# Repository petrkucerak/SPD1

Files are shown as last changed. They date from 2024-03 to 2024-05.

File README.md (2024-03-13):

# Weather station with geolocation

Authors: Petr Kucera, Lukas Nejezchleb

## Project description

### Goal and motivation

If you go for cold water swimming, it might be interesting for you to know the parameters of the particular river, stream, or pond. But how do you manage when the Czech Hydrometeorological Institute does not monitor the given watercourse? What if you could keep a diary that would not only collect the water and air temperature but also allow you to record how you felt on a particular day after the cold swimming?

The aim of this project is to create weather station capable of measuring temperature, humidity, water temperature, light. In addition, the station will be equipped with GPS sensor, so that the user can distinguish between data from different stations using positions in the map. 

### Use case
Various weather station projects are currently available. When we consider the requirement to have multiple weather stations (there can be quite different weather conditions in locations close-by, especially in mountainous terrain). Our approach, which uses GPS positioning to distinguish between different nodes, could help with that.

### Project architecture

For simplicity, let's divide the project into two environments: *river environment* and *house environment*.

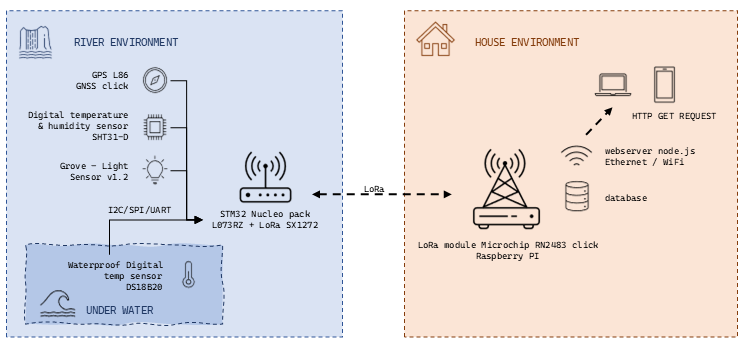
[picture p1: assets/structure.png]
project structure


The **river environment** includes a device that is placed on the riverbank. One sensor, measuring water temperature, is located in the water, while other sensors measuring temperature and humidity, position (GPS), and light are placed above the water. The device operates hourly and is powered by batteries. It sends data several times a day using LoRa technology. Code will be implemented in C/C++.

In the **house environment**, there is a device called the *concentrator*. It receives data from devices by the watercourse using LoRa technology and stores it in a database. The device is connected to the home network via RJ-45 or WiFi. It runs a web server that displays the measured results on a map. Handle routines will be implemented in C/C++/Python and server in JavaScript/Typescript.

## Requirements
To implement a weather station node, the following material is required
- STM32 Nucleo pack - L073RZ + LoRa SX1272 (*2x for parallel development*)
- GPS L86 - GNSS click
- SHT31-D Digital temperature & humidity sensor
- Grove - Light Sensor v1.2
- DS18B20 Waterproof Digital temp sensor 

For master bus collecting data from nodes
- Raspberry Pi 3 B + LoRa shield + 32GB SD

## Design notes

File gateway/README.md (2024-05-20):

# Gateway device

LoRa Gateway device runs on Raspberry PI.

## Connect to Raspberry PI

```sh
ssh pedro@192.168.0.178
ssh pedro@192.168.137.157
K&mo1234 # password
```

## Hardware

### Lora shield

- LoRa Gateway RPI/RFI
- pinout: https://electronilab.co/tienda/modulo-transceptor-rfm96w-hoperf-lora-ultra-long-range-433-mhz/
- datasheet: https://cdn-learn.adafruit.com/assets/assets/000/031/660/original/sx1272.pdf?1460518722

```
    H
   rf96
 17081714
1708122155
```

## Software

Uses https://github.com/adafruit/Adafruit_CircuitPython_RFM9x

```sh
python3 -m venv .venv
source .venv/bin/activate
pip3 install adafruit-circuitpython-rfm9x
```

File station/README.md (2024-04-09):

# Station device

Station runs on ST32 based board.

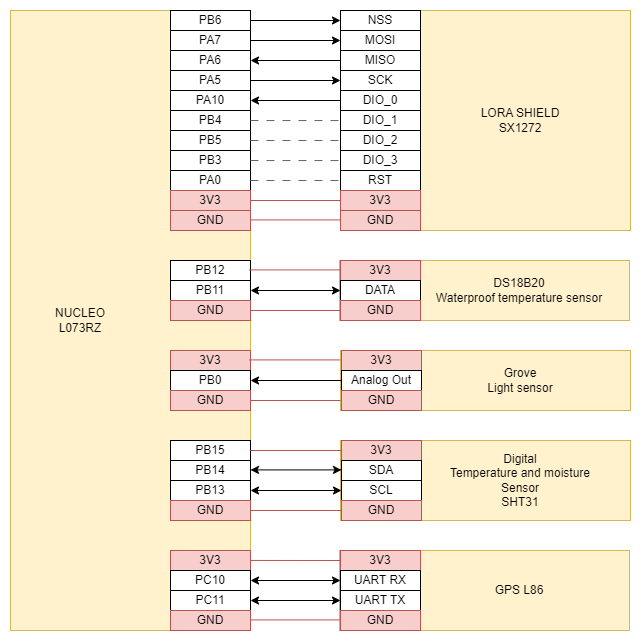
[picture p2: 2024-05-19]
station/Schematic.png

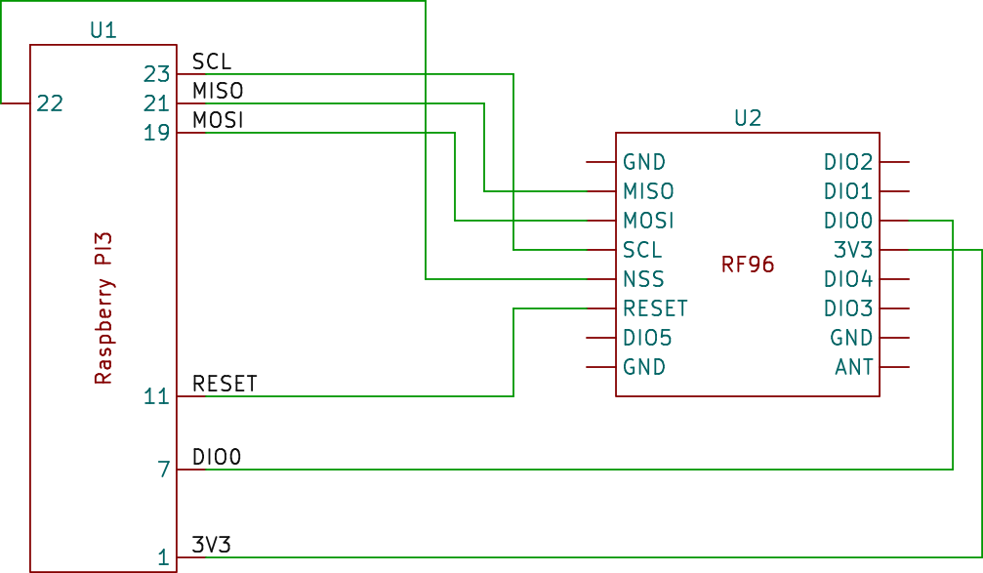
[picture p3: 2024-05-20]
gateway/gateway-schema/gateway-schema.png

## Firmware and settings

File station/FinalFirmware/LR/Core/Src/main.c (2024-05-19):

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
/* Includes ------------------------------------------------------------------*/
#include "main.h"

/* USER CODE BEGIN Includes */
#include <math.h>
#include <stdlib.h>
#include <stdio.h>

/* USER CODE END Includes */

/* USER CODE BEGIN PD */
#define SERVER 0
uint8_t data_rx [512] = {0};
uint8_t data_tx [512] = {0};
uint8_t last_data_received = 0;
uint16_t last_data_num;

/* USER CODE END PD */

 ADC_HandleTypeDef hadc;
DMA_HandleTypeDef hdma_adc;

I2C_HandleTypeDef hi2c2;

SPI_HandleTypeDef hspi1;

TIM_HandleTypeDef htim6;
TIM_HandleTypeDef htim21;

UART_HandleTypeDef huart2;
UART_HandleTypeDef huart4;
DMA_HandleTypeDef hdma_usart2_tx;
DMA_HandleTypeDef hdma_usart4_rx;

void SystemClock_Config(void);
static void MX_GPIO_Init(void);
static void MX_USART2_UART_Init(void);
static void MX_DMA_Init(void);
static void MX_USART4_UART_Init(void);
static void MX_ADC_Init(void);
static void MX_SPI1_Init(void);
static void MX_TIM6_Init(void);
static void MX_TIM21_Init(void);
static void MX_I2C2_Init(void);
/* USER CODE BEGIN 0 */
float last_valid_latt = 0;
float last_valid_long = 0;
float last_valid_time = 0;
char last_valid_ns = 0;
char last_valid_we = 0;

uint16_t last_transmission_ID = 0;
uint8_t last_transmission_Checksum = 0;
uint8_t last_transmission_BitwiseParity = 0;
uint8_t last_transmission_confirmed = 0;





#define RXBUFLEN  4096
#define ADCDATALEN 2
char rx_data [RXBUFLEN] = {0};
uint16_t last_rx = 0;
#define RXLINBUFLEN 128
char rx_lin_buf [RXLINBUFLEN+1]= {0};

char tempbuffer [] = "$GNGLL,5005.2816,N,01427.1765,E,102908.000,A,D*48\r\n";

#define TXBUFLEN 110
char txbuf [TXBUFLEN] = {0};

uint16_t adcdata [ADCDATALEN] = {0};


enum msg_types {msg_unknown, msg_gnss_pos, msg_gnss_sat, msg_gps_pos, msg_gps_sat};

char* str_msg_gnss_pos = "$GNGLL";
char* str_msg_gps__pos = "$GPGLL";


//functions

uint8_t random_bit(){
	return adcdata[1]&1;
}

uint16_t random_uin16_t(){
	uint16_t random_code = 0;
	for(int i=0; i<16; ++i){
		random_code = random_code<<1;
		random_code = random_code|random_bit();
		HAL_Delay(5);
	}
	return random_code;
}

uint8_t strings_match_six(char *a, char* b){
	for(int i=0; i<6; ++i){
		if(a[i]!= b[i]){
			return 0;
		}
	}
	return 1;
}



uint8_t get_msg_type(){
	uint8_t msg_type = msg_unknown;
	if(rx_lin_buf[0]=='$'){
		if(strings_match_six(rx_lin_buf, str_msg_gnss_pos)){
			msg_type = msg_gnss_pos;
		}
		if(strings_match_six(rx_lin_buf, str_msg_gps__pos)){
			msg_type = msg_gps_pos;
		}

	}
	return msg_type;
}

int transfer_to_lin_buf(){
	//transfers one gps message into linear buffer
	int i=0;
	int end_found = 0;
	for(i=0; i<RXLINBUFLEN;++i){
		int idx = (last_rx+i)%RXBUFLEN;
		if(rx_data[idx] == '*'){
			if(rx_data[(idx+1)%RXBUFLEN]!=0){
				if(rx_data[(idx+2)%RXBUFLEN]!=0){
					end_found = 1;
				}
			}
			break;
		}
	}
	if(end_found==1){
		for(int j=0; j<=i+4; ++j){
			int idx = (last_rx+j)%RXBUFLEN;
			rx_lin_buf[j] = rx_data[idx];
			rx_data[idx] = 0;
		}
		for(int j=i+4+1; j<RXLINBUFLEN; ++j){
			rx_lin_buf[j] = 0;
		}
		last_rx = (last_rx+i+5)%RXBUFLEN;
	}
	return end_found;
}

uint8_t decode_gps(float *lat, float *lon, float* time, char *ns, char *we){
	//returns 1 if data is valid
	char valid = 0;

	char *endptr;
	char* parsedtext = &rx_lin_buf[7];
	*lat = strtof(parsedtext, &endptr);
	if(endptr[1]!=','){
		*ns = endptr[1];
		endptr= endptr+3;
	}else{
		endptr = endptr+2;
	}
	parsedtext = endptr;
	*lon = strtof(parsedtext, &endptr);
	if(endptr[1]!=','){
		*we = endptr[1];
		endptr= endptr+3;
	}else{
		endptr = endptr+2;
	}

	parsedtext = endptr;
	*time = strtof(parsedtext, &endptr);
	if(endptr[1]!=','){
		valid = endptr[1];
		endptr= endptr+3;
	}else{
		endptr = endptr+2;
	}

	//convert the values to degrees
	*lat = *lat/100;
	*lat = (floor(*lat)+(*lat-floor(*lat))/60.0*100.0);
	*lon = *lon/100;
	*lon = (floor(*lon)+(*lon-floor(*lon))/60.0*100.0);
	return(valid == 'A');
}

void handle_gps(){
	while(transfer_to_lin_buf()){
		uint8_t msg_type=  get_msg_type();
		if(msg_type == msg_gnss_pos || msg_type== msg_gps_pos){
			float temp_lat = 0;
			float temp_time = 0;
			float temp_long = 0;
			char temp_ns =0;
			char temp_we =0;
			if(decode_gps(&temp_lat, &temp_long, &temp_time, &temp_ns, &temp_we)){
				last_valid_latt = temp_lat;
				last_valid_long = temp_long;
				last_valid_time = temp_time;
				last_valid_ns = temp_ns;
				last_valid_we = temp_we;
			}
		}
	}

}






void delay_us (uint32_t us)
{
    __HAL_TIM_SET_COUNTER(&htim21,0);
    while ((__HAL_TIM_GET_COUNTER(&htim21))<us);
}

uint8_t DS18B20_Start (void)
{
	uint8_t Response = 0;
	GPIOB->BRR |= TEMPSIG_Pin; //reset pin
	delay_us (480);   // delay according to datasheet
	GPIOB->BSRR |= TEMPSIG_Pin; //reset pin
	delay_us (80);    // delay according to datasheet

	if (!(HAL_GPIO_ReadPin (TEMPSIG_GPIO_Port, TEMPSIG_Pin))) Response = 1;    // if the pin is low i.e the presence pulse is detected
	else Response = 0;

	delay_us (400); // 480 us delay totally.

	return Response;
}

void DS18B20_Write (uint8_t data)
{

	for (int i=0; i<8; i++)
	{

		if ((data & (1<<i))!=0)  // if the bit is high
		{
			// write 1
			GPIOB->BRR |= TEMPSIG_Pin; //reset pin
			delay_us (1);  // wait for 1 us

			GPIOB->BSRR |= TEMPSIG_Pin; //reset pin
			delay_us (70);  // wait for 60 us
		}

		else  // if the bit is low
		{
			// write 0
			GPIOB->BRR |= TEMPSIG_Pin; //reset pin
			delay_us (70);  // wait for 60 us

			GPIOB->BSRR |= TEMPSIG_Pin; //reset pin
			delay_us (1);  // wait for 1 us
		}
	}

}

uint8_t DS18B20_Read (void)
{
	uint8_t value=0;
	HAL_GPIO_WritePin(TEMPSIG_GPIO_Port, TEMPSIG_Pin, GPIO_PIN_SET);

	for (int i=0;i<8;i++)
	{
		GPIOB->BRR |= TEMPSIG_Pin; //reset pin
		//HAL_GPIO_WritePin(TEMPSIG_GPIO_Port, TEMPSIG_Pin, GPIO_PIN_RESET);
		delay_us (1);  // wait for 3 us
		GPIOB->BSRR |= TEMPSIG_Pin; //reset pin
		delay_us (1);
		//HAL_GPIO_WritePin(TEMPSIG_GPIO_Port, TEMPSIG_Pin, GPIO_PIN_SET);
		if (HAL_GPIO_ReadPin (TEMPSIG_GPIO_Port, TEMPSIG_Pin))  // if the pin is HIGH
		{
			value |= 1<<i;  // read = 1
		}
		delay_us (70);  // wait for 60 us
	}
	return value;
}

float get_DS18B20_temp(void){

	float floattemp = 0;

	__disable_irq();  // disable all interrupts
		if(DS18B20_Start ()){ //sensor detected
		__enable_irq();   // enable all interrupts
		HAL_Delay (1);
		__disable_irq();  // disable all interrupts
		DS18B20_Write (0xCC);  // skip ROM
		DS18B20_Write (0x44);  // convert t
		__enable_irq();   // enable all interrupts
		HAL_Delay (800);
		__disable_irq();  // disable all interrupts
		if(DS18B20_Start ()){
			__enable_irq();   // enable all interrupts
					HAL_Delay (1);
					__disable_irq();  // disable all interrupts
			DS18B20_Write (0xCC);  // skip ROM
			DS18B20_Write (0xBE);  // Read Scratch-pad
			uint8_t Temp_byte1 = DS18B20_Read();
			uint8_t Temp_byte2 = DS18B20_Read();
			__enable_irq();   // enable all interrupts
			int16_t temp = Temp_byte1 | Temp_byte2<<8;
			floattemp = temp/8.0;
			floattemp = floattemp*0.5;
			asm("NOP");
		}

	}
		__enable_irq();   // enable all interrupts


	return floattemp;
}



void write_reg(uint8_t reg, uint8_t data){

	__disable_irq();
	HAL_GPIO_WritePin(LORA_CS_GPIO_Port, LORA_CS_Pin, GPIO_PIN_RESET);
	reg = reg|0x80;
	HAL_SPI_Transmit(&hspi1, &reg, 1, 1000);
	HAL_SPI_Transmit(&hspi1, &data, 1, 1000);
	HAL_GPIO_WritePin(LORA_CS_GPIO_Port, LORA_CS_Pin, GPIO_PIN_SET);
	__enable_irq();
}

uint8_t read_reg(uint8_t reg){
	__disable_irq();
	uint8_t data =0;
	HAL_GPIO_WritePin(LORA_CS_GPIO_Port, LORA_CS_Pin, GPIO_PIN_RESET);
	HAL_SPI_Transmit(&hspi1, &reg, 1, 1000);
	HAL_SPI_Receive(&hspi1, &data, 1, 1000);
	HAL_GPIO_WritePin(LORA_CS_GPIO_Port, LORA_CS_Pin, GPIO_PIN_SET);
	__enable_irq();
	return data;
}

void SetOpMode( uint8_t opMode )
{
    write_reg( REG_OPMODE, (read_reg( REG_OPMODE ) & RF_OPMODE_MASK ) | opMode );
}

void SetRfTxPower( int8_t power ,uint32_t freq)
{
    uint8_t paConfig = 0;
    uint8_t paDac = 0;

    paConfig = read_reg( REG_PACONFIG );
    paDac = read_reg( REG_PADAC );

    paConfig = ( paConfig & RF_PACONFIG_PASELECT_MASK ) | RF_PACONFIG_PASELECT_RFO;

    if( ( paConfig & RF_PACONFIG_PASELECT_PABOOST ) == RF_PACONFIG_PASELECT_PABOOST )
    {
        if( power > 17 )
        {
            paDac = ( paDac & RF_PADAC_20DBM_MASK ) | RF_PADAC_20DBM_ON;
        }
        else
        {
            paDac = ( paDac & RF_PADAC_20DBM_MASK ) | RF_PADAC_20DBM_OFF;
        }
        if( ( paDac & RF_PADAC_20DBM_ON ) == RF_PADAC_20DBM_ON )
        {
            if( power < 5 )
            {
                power = 5;
            }
            if( power > 20 )
            {
                power = 20;
            }
            paConfig = ( paConfig & RFLR_PACONFIG_OUTPUTPOWER_MASK ) | ( uint8_t )( ( uint16_t )( power - 5 ) & 0x0F );
        }
        else
        {
            if( power < 2 )
            {
                power = 2;
            }
            if( power > 17 )
            {
                power = 17;
            }
            paConfig = ( paConfig & RFLR_PACONFIG_OUTPUTPOWER_MASK ) | ( uint8_t )( ( uint16_t )( power - 2 ) & 0x0F );
        }
    }
    else
    {
        if( power < -1 )
        {
            power = -1;
        }
        if( power > 14 )
        {
            power = 14;
        }
        paConfig = ( paConfig & RFLR_PACONFIG_OUTPUTPOWER_MASK ) | ( uint8_t )( ( uint16_t )( power + 1 ) & 0x0F );
    }
    write_reg( REG_PACONFIG, paConfig );
    write_reg( REG_PADAC, paDac );
}



void set_for_rx(uint32_t bandwidth,
        uint32_t datarate, uint8_t coderate,
        uint32_t bandwidthAfc, uint16_t preambleLen,
        uint16_t symbTimeout, uint8_t fixLen,
        uint8_t payloadLen,
		uint8_t crcOn, uint8_t freqHopOn, uint8_t hopPeriod,
		uint8_t iqInverted, uint8_t rxContinuous ){

    	SetOpMode( RF_OPMODE_SLEEP );
	    write_reg( REG_OPMODE, (read_reg( REG_OPMODE ) & RFLR_OPMODE_LONGRANGEMODE_MASK ) | RFLR_OPMODE_LONGRANGEMODE_ON );

	    write_reg( REG_DIOMAPPING1, 0x00 );
	    write_reg( REG_DIOMAPPING2, 0x00 );
		write_reg(REG_LR_FIFORXBASEADDR, 0x00); //half of fifo for rx

	uint8_t LowDatarateOptimize=0;
    if( datarate > 12 )
    {
        datarate = 12;
    }
    else if( datarate < 6 )
    {
        datarate = 6;
    }

    if( ( ( bandwidth == 0 ) && ( ( datarate == 11 ) || ( datarate == 12 ) ) ) ||
        ( ( bandwidth == 1 ) && ( datarate == 12 ) ) )
    {
    	LowDatarateOptimize = 0x01;
    }
    else
    {
    	LowDatarateOptimize = 0x00;
    }

    write_reg( REG_LR_MODEMCONFIG1,
                 ( read_reg( REG_LR_MODEMCONFIG1 ) &
                   RFLR_MODEMCONFIG1_BW_MASK &
                   RFLR_MODEMCONFIG1_CODINGRATE_MASK &
                   RFLR_MODEMCONFIG1_IMPLICITHEADER_MASK &
                   RFLR_MODEMCONFIG1_RXPAYLOADCRC_MASK &
                   RFLR_MODEMCONFIG1_LOWDATARATEOPTIMIZE_MASK ) |
                   ( bandwidth << 6 ) | ( coderate << 3 ) |
                   ( fixLen << 2 ) | ( crcOn << 1 ) |
				   LowDatarateOptimize );

    write_reg( REG_LR_MODEMCONFIG2,
                 ( read_reg( REG_LR_MODEMCONFIG2 ) &
                   RFLR_MODEMCONFIG2_SF_MASK &
                   RFLR_MODEMCONFIG2_SYMBTIMEOUTMSB_MASK ) |
                   ( datarate << 4 ) |
                   ( ( symbTimeout >> 8 ) & ~RFLR_MODEMCONFIG2_SYMBTIMEOUTMSB_MASK ) );

    write_reg( REG_LR_SYMBTIMEOUTLSB, ( uint8_t )( symbTimeout & 0xFF ) );

    write_reg( REG_LR_PREAMBLEMSB, ( uint8_t )( ( preambleLen >> 8 ) & 0xFF ) );
    write_reg( REG_LR_PREAMBLELSB, ( uint8_t )( preambleLen & 0xFF ) );

    if( fixLen == 1 )
    {
        write_reg( REG_LR_PAYLOADLENGTH, payloadLen );
    }

    if(freqHopOn)
    {
        write_reg( REG_LR_PLLHOP, ( read_reg( REG_LR_PLLHOP ) & RFLR_PLLHOP_FASTHOP_MASK ) | RFLR_PLLHOP_FASTHOP_ON );
        write_reg( REG_LR_HOPPERIOD, hopPeriod );
    }

    if( datarate == 6 )
    {
        write_reg( REG_LR_DETECTOPTIMIZE,
                     ( read_reg( REG_LR_DETECTOPTIMIZE ) &
                       RFLR_DETECTIONOPTIMIZE_MASK ) |
                       RFLR_DETECTIONOPTIMIZE_SF6 );
        write_reg( REG_LR_DETECTIONTHRESHOLD,
                     RFLR_DETECTIONTHRESH_SF6 );
    }
    else
    {
        write_reg( REG_LR_DETECTOPTIMIZE,
                     ( read_reg( REG_LR_DETECTOPTIMIZE ) &
                     RFLR_DETECTIONOPTIMIZE_MASK ) |
                     RFLR_DETECTIONOPTIMIZE_SF7_TO_SF12 );
        write_reg( REG_LR_DETECTIONTHRESHOLD,
                     RFLR_DETECTIONTHRESH_SF7_TO_SF12 );
    }
}

void set_for_tx(int8_t power, uint32_t fdev,
                        uint32_t bandwidth, uint32_t datarate,
                        uint8_t coderate, uint16_t preambleLen,
						uint8_t fixLen, uint8_t crcOn, uint8_t freqHopOn,
                        uint8_t hopPeriod, uint8_t iqInverted, uint32_t timeout )
{
	SetOpMode( RF_OPMODE_SLEEP );
	write_reg( REG_OPMODE, (read_reg( REG_OPMODE ) & RFLR_OPMODE_LONGRANGEMODE_MASK ) | RFLR_OPMODE_LONGRANGEMODE_ON );

	write_reg( REG_DIOMAPPING1, 0x00 );
	write_reg( REG_DIOMAPPING2, 0x00 );
	write_reg(REG_LR_FIFOTXBASEADDR, 0x80); //half of fifo for tx



	uint8_t LowDatarateOptimize=0;
	if( datarate > 12 )
	{
	    datarate = 12;
		}
	else if( datarate < 6 )
	{
	    datarate = 6;
	}
	if( ( ( bandwidth == 0 ) && ( ( datarate == 11 ) || ( datarate == 12 ) ) ) ||
	( ( bandwidth == 1 ) && ( datarate == 12 ) ) )
	{
		LowDatarateOptimize = 0x01;
	}
	else
	{
		LowDatarateOptimize = 0x00;
	}

	if(freqHopOn)
	{
		write_reg( REG_LR_PLLHOP, ( read_reg( REG_LR_PLLHOP ) & RFLR_PLLHOP_FASTHOP_MASK ) | RFLR_PLLHOP_FASTHOP_ON );
	    write_reg( REG_LR_HOPPERIOD,hopPeriod );
	}

	write_reg( REG_LR_MODEMCONFIG1,
	                         ( read_reg( REG_LR_MODEMCONFIG1 ) &
	                           RFLR_MODEMCONFIG1_BW_MASK &
	                           RFLR_MODEMCONFIG1_CODINGRATE_MASK &
	                           RFLR_MODEMCONFIG1_IMPLICITHEADER_MASK &
	                           RFLR_MODEMCONFIG1_RXPAYLOADCRC_MASK &
	                           RFLR_MODEMCONFIG1_LOWDATARATEOPTIMIZE_MASK ) |
	                           ( bandwidth << 6 ) | ( coderate << 3 ) |
	                           ( fixLen << 2 ) | ( crcOn << 1 ) |
							   LowDatarateOptimize);

	write_reg( REG_LR_MODEMCONFIG2,
	                        ( read_reg( REG_LR_MODEMCONFIG2 ) &
	                          RFLR_MODEMCONFIG2_SF_MASK ) |
	                          ( datarate << 4 ) );


	write_reg( REG_LR_PREAMBLEMSB, ( preambleLen >> 8 ) & 0x00FF );
	write_reg( REG_LR_PREAMBLELSB, preambleLen & 0xFF );

	if( datarate == 6 )
	{
		write_reg( REG_LR_DETECTOPTIMIZE,
				( read_reg( REG_LR_DETECTOPTIMIZE ) &
						RFLR_DETECTIONOPTIMIZE_MASK ) |
						RFLR_DETECTIONOPTIMIZE_SF6 );
	            write_reg( REG_LR_DETECTIONTHRESHOLD,
	                    RFLR_DETECTIONTHRESH_SF6 );
	}
	else
	{
		write_reg( REG_LR_DETECTOPTIMIZE,
				( read_reg( REG_LR_DETECTOPTIMIZE ) &
						RFLR_DETECTIONOPTIMIZE_MASK ) |
	                    RFLR_DETECTIONOPTIMIZE_SF7_TO_SF12 );
		write_reg( REG_LR_DETECTIONTHRESHOLD,
				RFLR_DETECTIONTHRESH_SF7_TO_SF12 );
	}

}

void set_channel(uint32_t freq){
	freq = ( uint32_t )( ( double )freq / ( double )FREQ_STEP );
	    write_reg( REG_FRFMSB, ( uint8_t )( ( freq >> 16 ) & 0xFF ) );
	    write_reg( REG_FRFMID, ( uint8_t )( ( freq >> 8 ) &  0xFF ) );
	    write_reg( REG_FRFLSB, ( uint8_t )( freq & 0xFF ) );
}

void Write( uint8_t addr, uint8_t *buffer, uint8_t size )
{
	addr = addr | 0x80;
	__disable_irq();
	HAL_GPIO_WritePin(LORA_CS_GPIO_Port, LORA_CS_Pin, GPIO_PIN_RESET);
    HAL_SPI_Transmit(&hspi1, &addr, 1, 1000);
    HAL_SPI_Transmit(&hspi1, buffer, size, 1000);
    HAL_GPIO_WritePin(LORA_CS_GPIO_Port, LORA_CS_Pin, GPIO_PIN_SET);
    __enable_irq();

}

void WriteFifo( uint8_t *buffer, uint8_t size )
{
    Write( 0, buffer, size );
}


void lora_tx(uint8_t freqHopOn)
{

            if(freqHopOn)
            {
                write_reg( REG_LR_IRQFLAGSMASK, RFLR_IRQFLAGS_RXTIMEOUT |
                                                  RFLR_IRQFLAGS_RXDONE |
                                                  RFLR_IRQFLAGS_PAYLOADCRCERROR |
                                                  RFLR_IRQFLAGS_VALIDHEADER |
                                                  //RFLR_IRQFLAGS_TXDONE |
                                                  RFLR_IRQFLAGS_CADDONE |
                                                  //RFLR_IRQFLAGS_FHSSCHANGEDCHANNEL |
                                                  RFLR_IRQFLAGS_CADDETECTED );

                // DIO0=TxDone, DIO2=FhssChangeChannel
                write_reg( REG_DIOMAPPING1, (read_reg( REG_DIOMAPPING1 ) & RFLR_DIOMAPPING1_DIO0_MASK & RFLR_DIOMAPPING1_DIO2_MASK ) | RFLR_DIOMAPPING1_DIO0_01 | RFLR_DIOMAPPING1_DIO2_00 );
            }
            else
            {
                write_reg( REG_LR_IRQFLAGSMASK, RFLR_IRQFLAGS_RXTIMEOUT |
                                                  RFLR_IRQFLAGS_RXDONE |
                                                  RFLR_IRQFLAGS_PAYLOADCRCERROR |
                                                  RFLR_IRQFLAGS_VALIDHEADER |
                                                  //RFLR_IRQFLAGS_TXDONE |
                                                  RFLR_IRQFLAGS_CADDONE |
                                                  RFLR_IRQFLAGS_FHSSCHANGEDCHANNEL |
                                                  RFLR_IRQFLAGS_CADDETECTED );

                // DIO0=TxDone
                write_reg( REG_DIOMAPPING1, (read_reg( REG_DIOMAPPING1 ) & RFLR_DIOMAPPING1_DIO0_MASK ) | RFLR_DIOMAPPING1_DIO0_01 );
            }




	SetOpMode( RF_OPMODE_TRANSMITTER );
}
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
int main(void)
{
  /* MCU Configuration--------------------------------------------------------*/

  /* Reset of all peripherals, Initializes the Flash interface and the Systick. */
  HAL_Init();

  /* Configure the system clock */
  SystemClock_Config();

  /* Initialize all configured peripherals */
  MX_GPIO_Init();
  MX_USART2_UART_Init();
  MX_DMA_Init();
  MX_USART4_UART_Init();
  MX_ADC_Init();
  MX_SPI1_Init();
  MX_TIM6_Init();
  MX_TIM21_Init();
  MX_I2C2_Init();
  /* USER CODE BEGIN 2 */

  HAL_UART_Receive_DMA(&huart4, rx_data, RXBUFLEN);
  HAL_ADCEx_Calibration_Start(&hadc, ADC_SINGLE_ENDED);
  HAL_GPIO_WritePin(TEMPMOISTSENON_GPIO_Port, TEMPMOISTSENON_Pin, GPIO_PIN_SET); //turn on moisture sensor
  HAL_GPIO_WritePin(TEMPPWRT_GPIO_Port, TEMPPWRT_Pin, GPIO_PIN_SET); //turn on temp sensor
  HAL_Delay(100);
  HAL_ADC_Start_DMA(&hadc, adcdata, ADCDATALEN);
  HAL_TIM_Base_Start(&htim6);
  HAL_TIM_Base_Start(&htim21);





  set_channel(RF_FREQUENCY);

  set_for_rx(LORA_BANDWIDTH, LORA_SPREADING_FACTOR,
                           LORA_CODINGRATE, 0, LORA_PREAMBLE_LENGTH,
                           LORA_SYMBOL_TIMEOUT, LORA_FIX_LENGTH_PAYLOAD_ON, 0,
                           LORA_CRC_ENABLED, LORA_FHSS_ENABLED, LORA_NB_SYMB_HOP,
                           LORA_IQ_INVERSION_ON, 1 );
  set_for_tx(TX_OUTPUT_POWER, 0, LORA_BANDWIDTH,
                       LORA_SPREADING_FACTOR, LORA_CODINGRATE,
                       LORA_PREAMBLE_LENGTH, LORA_FIX_LENGTH_PAYLOAD_ON,
                       LORA_CRC_ENABLED, LORA_FHSS_ENABLED, LORA_NB_SYMB_HOP,
                       LORA_IQ_INVERSION_ON, 2000 );




  /* USER CODE END 2 */

  /* Infinite loop */
  /* USER CODE BEGIN WHILE */




  uint8_t receive_buffer[32] = {0};
  uint8_t receive_buffer_ptr = 0;
  uint8_t last_receive_ptr = 0;
  while (1)
  	  {

	  	  //prepare data_to_send
	  	  float temp =  get_DS18B20_temp();
	  	  uint8_t i2c_data [10] = {0};
	  	  HAL_I2C_Mem_Read(&hi2c2, 0x44<<1, 0x2C06, 2, i2c_data, 6, 1000);
	  	  float moisttemp = -45+175*((i2c_data[0]<<8)|i2c_data[1])/((1<<16)-1.0);
	  	  float moistmois = 100*((i2c_data[3]<<8)|i2c_data[4])/((1<<16)-1.0);


	  	  int j = snprintf(txbuf, TXBUFLEN, "    Tw=%.1f;"
			  	  	  	  	  	  	  	  "Ta=%.1f;"
			  	  	  	  	  	  	  	  "Ma=%.1f;"
			  	  	  	  	  	  	  	  "Lo=%u;"
			  	  	  	  	  	  	  	  "G%c=%.6f;"
	  			  	  	  	  	  	  	  "G%c=%.6f  ",
			  	  	  	  	  	  	  	   temp, moisttemp, moistmois,
										  	  adcdata[0],
											  last_valid_ns,last_valid_latt,
											  last_valid_we,last_valid_long);

	  	  //quickly send data
	  	  uint16_t msg_len = j;
	  	  uint16_t random_ID = random_uin16_t();
	  	  last_transmission_ID = random_ID;

	  	  txbuf[0] = random_ID&0xff;
	  	  txbuf[1] = random_ID>>8;
	  	  txbuf[2] = msg_len>>8;
	  	  txbuf[3] = msg_len&0xff;
	  	  //calculate checksum
	  	  uint8_t sum = 0;
	  	  for(int i=0; i<msg_len-2; ++i){
	  		  sum = sum+txbuf[i];
	  	  }
	  	  txbuf[msg_len-2] = 256-sum;
	  	  last_transmission_Checksum = 256-sum;

	  	  //calculate bitwise parity
	  	  uint8_t parity =0;
	  	  for(int i=0; i<msg_len-1; ++i){
	  		parity = parity^txbuf[i];
	  	  }
	  	  txbuf[msg_len-1] = parity;
	  	  last_transmission_BitwiseParity=parity;
	  	  last_transmission_confirmed = 0;


	  	  //send until transmission confirmed, maximum 5 times
	  	  for(int transmissionNo = 0; transmissionNo<5; transmissionNo++){
	  		lora_send(txbuf, j, LORA_FHSS_ENABLED, LORA_IQ_INVERSION_ON);
	  		uint8_t status_val = read_reg(1);
	  		while((status_val &0xf) ==0x3){//while transmission in progess
	  		 	  status_val = read_reg(1);
	  		}
	  		//CLEAR TX COMPLETE INTERRUPT
	  		write_reg(REG_LR_IRQFLAGS, 0x8);
	  		lora_rx(1000, LORA_IQ_INVERSION_ON, 1, LORA_FHSS_ENABLED);
	  		HAL_Delay(200+100*transmissionNo);
	  		if(last_transmission_confirmed){
	  			break;
	  		}
	  	  }
	  	  HAL_Delay(10000);



		  SetOpMode(RF_OPMODE_STANDBY);



    /* USER CODE END WHILE */

    /* USER CODE BEGIN 3 */
  }
  /* USER CODE END 3 */
}

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


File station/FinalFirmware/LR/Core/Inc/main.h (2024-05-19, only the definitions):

#define RF_FREQUENCY                                    868000000 // Hz
#define TX_OUTPUT_POWER                                 14        // 14 dBm
#define LORA_BANDWIDTH                              2         // [0: 125 kHz,
#define LORA_SPREADING_FACTOR                       7         // [SF7..SF12]
#define LORA_CODINGRATE                             1         // [1: 4/5,
#define LORA_PREAMBLE_LENGTH                        8         // Same for Tx and Rx
#define LORA_SYMBOL_TIMEOUT                         5         // Symbols
#define LORA_FIX_LENGTH_PAYLOAD_ON                  0
#define LORA_FHSS_ENABLED                           0
#define LORA_NB_SYMB_HOP                            4
#define LORA_IQ_INVERSION_ON                        0
#define LORA_CRC_ENABLED                            1
#define B1_Pin GPIO_PIN_13
#define B1_GPIO_Port GPIOC
#define B1_EXTI_IRQn EXTI4_15_IRQn
#define MCO_Pin GPIO_PIN_0
#define MCO_GPIO_Port GPIOH
#define TEMPSIG_Pin GPIO_PIN_11
#define TEMPSIG_GPIO_Port GPIOB
#define TEMPPWRT_Pin GPIO_PIN_12
#define TEMPPWRT_GPIO_Port GPIOB
#define TEMPMOISTSENON_Pin GPIO_PIN_15
#define TEMPMOISTSENON_GPIO_Port GPIOB
#define TMS_Pin GPIO_PIN_13
#define TMS_GPIO_Port GPIOA
#define TCK_Pin GPIO_PIN_14
#define TCK_GPIO_Port GPIOA
#define LORA_CS_Pin GPIO_PIN_6
#define LORA_CS_GPIO_Port GPIOB

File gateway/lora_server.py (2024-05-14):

import board
import busio
import digitalio
from datetime import datetime
import os
import json
import time
import adafruit_rfm9x

# Define radio parameters.
RADIO_FREQ_MHZ = 868.0  # Frequency of the radio in Mhz. Must match your

# Define pins connected to the chip, use these if wiring up the breakout according to the guide:
CS = digitalio.DigitalInOut(board.D25)
RESET = digitalio.DigitalInOut(board.D17)

# Initialize SPI bus.
spi = busio.SPI(board.D11, MOSI=board.D10, MISO=board.D9)

# Initialze RFM radio
rfm9x = adafruit_rfm9x.RFM9x(spi, CS, RESET, RADIO_FREQ_MHZ,  # must specify parameters
                             preamble_length=8,  # The length in bytes of the packet preamble
                             high_power=True,  # Boolean to indicate a high power board
                             baudrate=5000000,  # Baud rate of the SPI connection
                             # Boolean to Enable/Disable Automatic Gain Control - Default=False (AGC off)
                             agc=False,
                             # Boolean to Enable/Disable Cyclic Redundancy Check - Default=True (CRC Enabled)
                             crc=True
                             )

rfm9x.tx_power = 23
rfm9x.signal_bandwidth = 500000
rfm9x.spreading_factor = 7
rfm9x.coding_rate = 5  # 4/5

print("Waiting for packets...")

# Save log as a txt
if not os.path.exists("../logs"):
    os.makedirs("../logs")

def run():
    while True:
        # Attempt to receive a packet with a timeout of 20 seconds
        packet = rfm9x.receive(keep_listening=True, timeout=20.0, with_header=True)
        now = datetime.now() # Get the current time
        if packet is None:
            # No packet received
            print(now.strftime("%H:%M:%S"), "|",
                "Received nothing! Listening again...")
        else:
            # Packet received
            # 2b - message_id (binary) | 2b - message_size (binary) | message (string) | 1b - checksum (binary modulo 255) | 1b - bitwise parity
            print()
            print("Packet:", packet)
            message_id = int.from_bytes(packet[:2], byteorder='big', signed=False)
            message_size = int.from_bytes(packet[2:4], byteorder='big', signed=False)
            message_end = message_size - 2
            message = str(packet[4:message_end], "utf-8")
            checksum = int.from_bytes(packet[message_end:message_end+1], byteorder='big', signed=False)
            bwp = int.from_bytes(packet[message_end+1:message_end+2], byteorder='big', signed=False)


            print("Message ID:", message_id)
            print("Message size:", message_size)
            print("Message:", message)
            print("Checksum:", checksum)
            print("Bwp:", bwp)

            # Calculate checksum
            for i in range(message_end + 1):
                checksum_local = int(packet[i])
            checksum_local = checksum_local % 256
            print("Checksum local:", checksum_local)

            if(checksum_local != checksum):
                print("ERROR: wrong checksum")
                continue

            # Calculate bitwise parity
            bwp_local = 0
            for i in range(message_size - 1):
                bwp_local = bwp_local ^ packet[i]
            print("Bitwise parity local:", bwp_local)

            if(bwp_local != bwp):
                print("ERROR: wrong bwp")
                continue


            # Send ACK
            ack = bytearray(7)
            ack[:2] = packet[:2]
            ack[2] = 0x41 # 'A'
            ack[3] = 0x43 # 'C'
            ack[4] = 0x4B # 'K'
            ack[5] = checksum_local
            ack[6] = bwp_local

            rfm9x.send(bytes(ack))
        

            # Save log to file
            pathname = f'../logs/{now.strftime("%Y-%m-%d")}.log'
            data = message.replace("\n\r\x00", "").split(";")
            json_data = {}
            for i in data:
                key, value = i.split("=")
                json_data[key] = value
            json_data["time"] = now.strftime("%Y-%m-%d %H:%M:%S")
            print(json_data)
            with open(pathname, "a+") as f:
                f.write(json.dumps(json_data) + ",\n")
    pass

# Main loop to run the script, restarting if an error occurs
while True:
    try:
        run()
        break
    except Exception as e:
        print(f"Error occurred: {e}. Restarting the script...")
        time.sleep(5)

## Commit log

2024-05-14 Implement LoRa Gateway (#4)
    * Describe used shield
    * Define password
    * Create template file
    * Update example script
    * Add simple test
    * Update script
    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
2024-05-15 Create server for data visualization (#3)
    * Define project structure
    * Clean project structure
    * Create header & footer component
    * Add content to structures
    * Create simple about page
    * Create script for data generation
    * Update data
    * Define command for server starting
    * Comment problematic part for Raspberry testing
    * Degrade next version
    * Remove old favicon
    * ADd github logo
    * Remove map implementation
    * Remove unused libraries
    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
2024-05-19 Added node schematic and firmware
2024-05-20 Create Gateway schema
    [gateway-schema.kicad_pcb, gateway-schema.kicad_sch]

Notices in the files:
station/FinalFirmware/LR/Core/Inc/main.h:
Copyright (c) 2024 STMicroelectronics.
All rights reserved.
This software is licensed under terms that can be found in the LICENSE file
